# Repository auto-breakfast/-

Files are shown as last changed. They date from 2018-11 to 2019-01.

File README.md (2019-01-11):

Auto_breakfast
===

## 應用情境
應用情境： 以PIC18做為整個作品的核心，以時鐘IC當計時器並在七段顯示器上顯示剩餘時間，再用手機以藍芽做為溝通橋樑傳送資料到PIC18 時間到點以後控制伺服馬達轉動角度來啟動電鍋、吐司機等等 
## 硬體架構
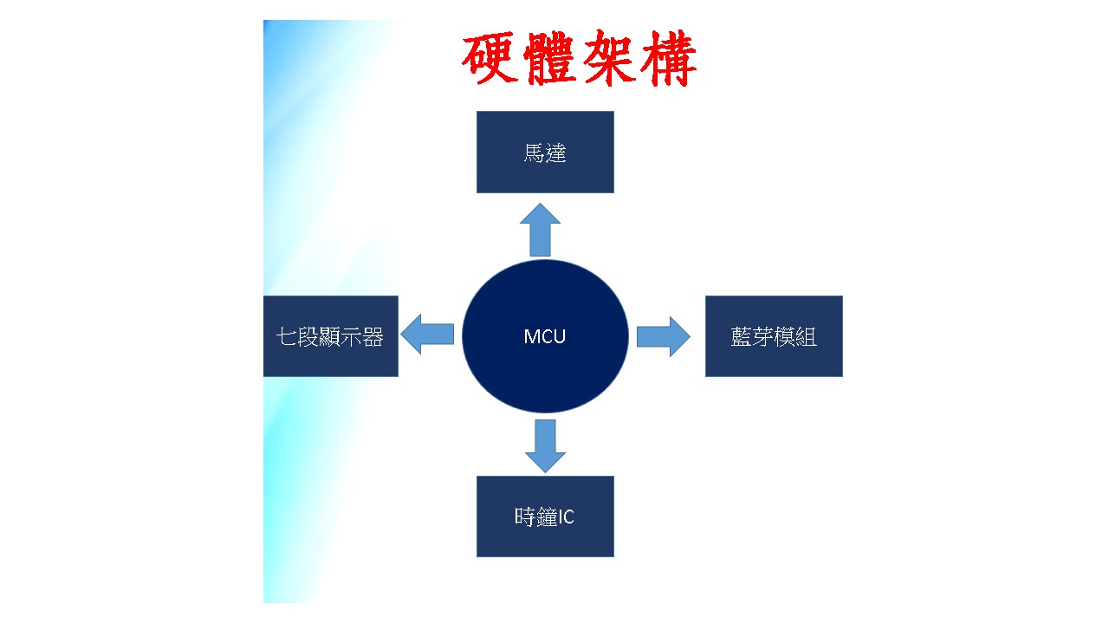
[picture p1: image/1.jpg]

## 軟體架構
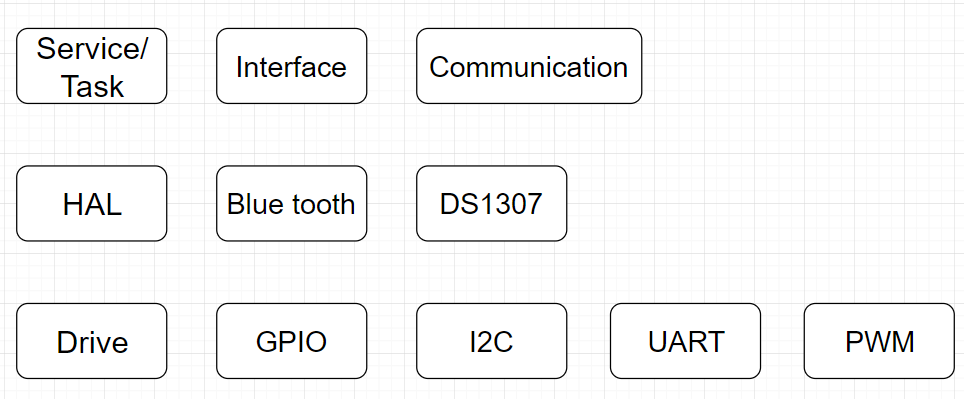
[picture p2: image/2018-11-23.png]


# 使用晶片
 ## MCU [PIC18F4520](https://github.com/auto-breakfast/auto-breakfast/raw/1105192112-patch-%E7%B5%B1%E6%95%B4/doc/39631E.pdf)


# 周邊
 ## 藍芽模組 [HC-05](http://www.electronicaestudio.com/docs/istd016A.pdf)


  ## 時鐘模組 [DS1302](https://github.com/auto-breakfast/auto-breakfast/raw/1105192112-patch-%E7%B5%B1%E6%95%B4/doc/DS1307.pdf)


 ## 伺服馬達 [MG995](https://github.com/auto-breakfast/auto-breakfast/raw/1105192112-patch-%E7%B5%B1%E6%95%B4/doc/MG995_Tower-Pro.pdf)


 ## 七段顯示器 [3641AH BH](https://github.com/auto-breakfast/auto-breakfast/raw/1105192112-patch-%E7%B5%B1%E6%95%B4/doc/3641AHBH.pdf)


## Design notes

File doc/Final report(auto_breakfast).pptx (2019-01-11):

## Auto_breakfast

組長:黃舜琦 組員:黃冠晉、呂睿紘

## 應用情境

- 應用情境： 以PIC18做為整個作品的核心，以時鐘IC當計時器並在七段顯示器上顯示剩餘時間，再用手機以藍芽做為溝通橋樑傳送資料到PIC18 時間到點以後控制伺服馬達轉動角度來啟動電鍋、吐司機等等

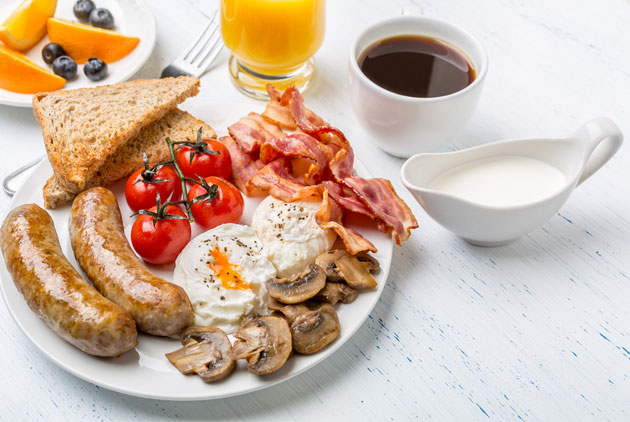
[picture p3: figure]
一張含有 桌, 食物, 杯子, 盤 的圖片 自動產生的描述

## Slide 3

伺服馬達
MG995

PWM

HC-05

GPIO

PIC18F4520

UART

七段顯示

I2C

RTC

## 軟體架構

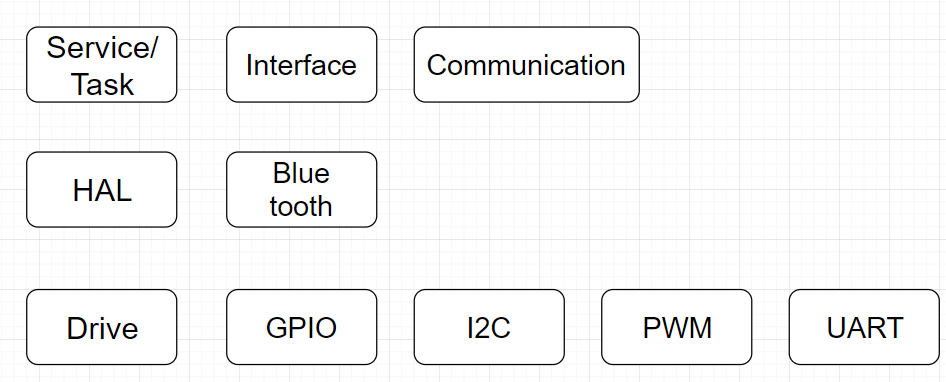
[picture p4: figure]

## 硬體接線圖

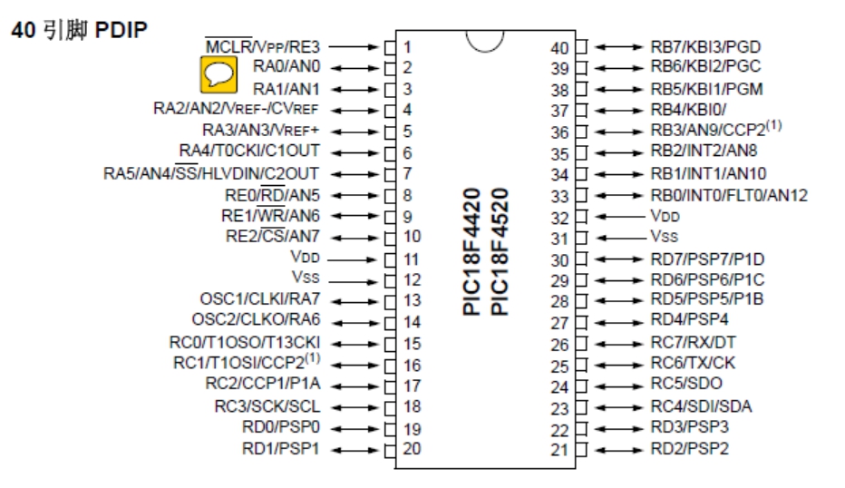
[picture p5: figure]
一張含有 文字 的圖片 自動產生的描述
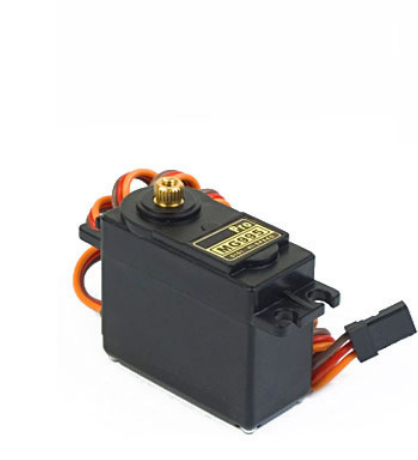
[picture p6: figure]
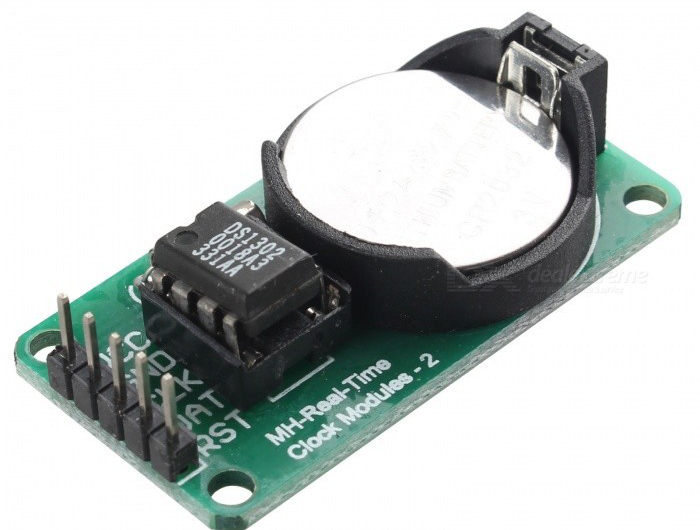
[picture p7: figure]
一張含有 電子用品, 電路 的圖片 自動產生的描述
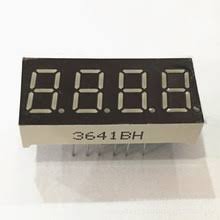
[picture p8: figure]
一張含有 物件 的圖片 自動產生的描述
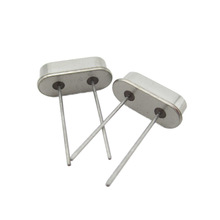
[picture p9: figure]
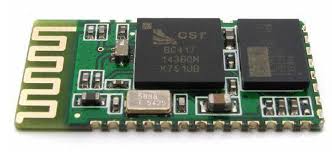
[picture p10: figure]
一張含有 電子用品, 電路 的圖片 自動產生的描述

## 硬體模型

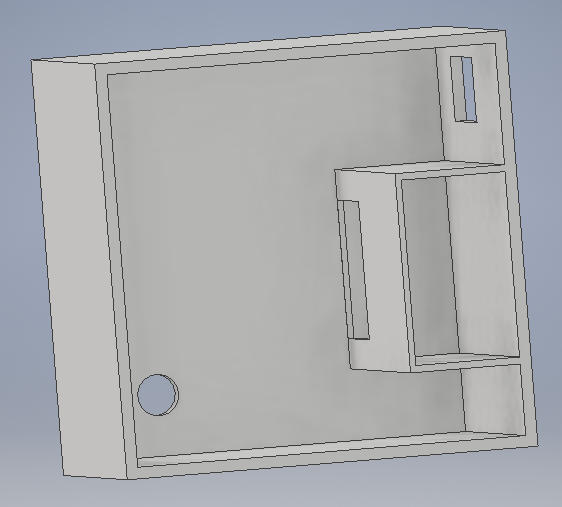
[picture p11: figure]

整體模型架構(固定伺服馬達)
電路板放置模型中
七段顯示器顯示時間處

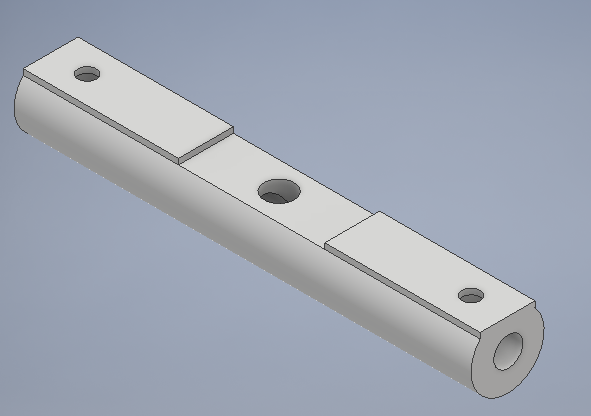
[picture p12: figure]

伺服馬達葉片上碳棒固定管

## 韌體實驗電路

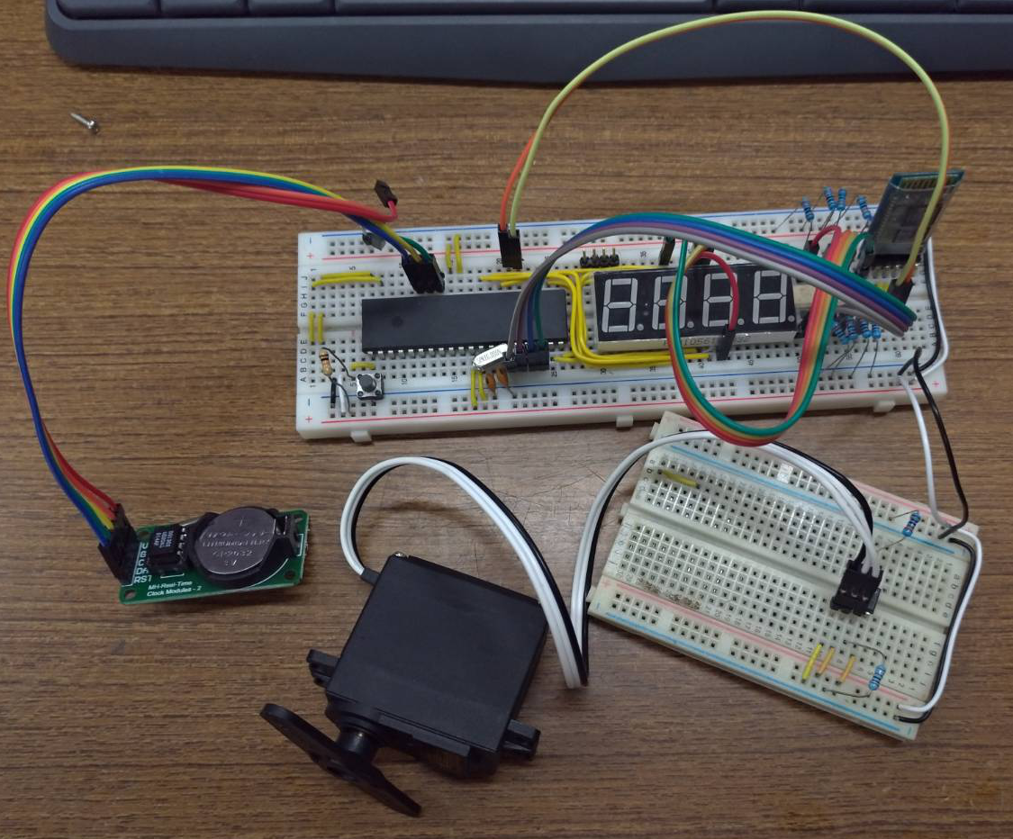
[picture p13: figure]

## 遇到的問題

遇到的問題：
1. 一開始不知道data有無順利輸出。
2. 再和其他程式做結合時，回傳值有時會回傳錯誤(時好時壞)

- UART篇

解決方法：
1. 檢查UART相關registers是否有設定錯誤
2. 使用邏輯分析儀和示波器檢查MCU接收到的資料示是否有錯誤
3. 善加使用debug模式檢查資料輸入及回傳

## 遇到的問題

- PWM篇

遇到的問題：
由於我們所使用的伺服馬達所需的PWM週期為20ms(50Hz)，而PIC18為8位元的處理器，性能較差無法除頻除至50Hz這麼低。

解決方法：
1. 將MCU的頻率降低，但嚴重影響到整體運行效能。(不採用)
2. 使用TIMER去時做出PWM，例:將TIMER設置為0.5ms觸發一次中斷搭配著couter和GPIO輸出。

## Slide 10

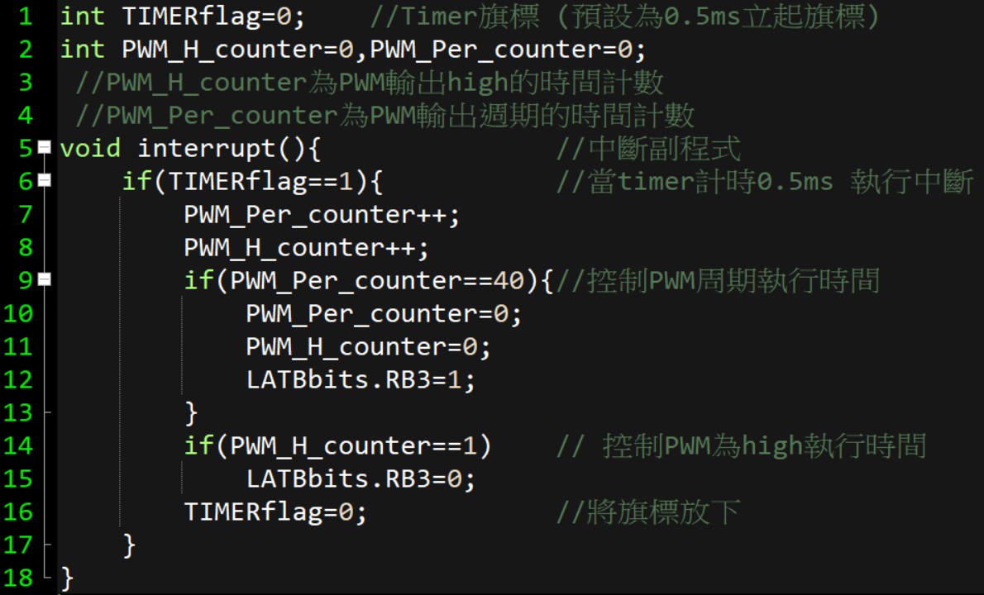
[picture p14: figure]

## 遇到的問題

- RTC篇
在讀Datasheet的時候上面圖說寫地址再給時脈就可以讀去那位址的資訊，可在寫時發現讀不出來，後來去網路上找範例後，發現他是打初始地址然後給8個1BYTE時脈一次把所有時間讀出來，隨後我就用PIC18模擬出波形，解決這問題。

整合篇
當把各自的程式打完做整合時，發現本身在時脈上的設定有所差異，所以在把UART加進去時程式無法正常動作，改好後則是換PWM加進來後的問題，但就像老師說的可以用中斷旗標來控制，後來我有想到可以用TIMER的旗標然後累加控制RTC讓他每10秒來抓值，剩餘的時間給七段顯示器去掃描，這樣的話七段顯示器就不會這麼暗了。

## 學習心得

- 這個學期修這門課以為是會教更多微處理機的延伸課程，結果沒想到是做小專題，壓力其實不小，因為課業、專題，然後又要做小專題，其實是很累的，不過也讓我們學習到如何分配時間去平衡這些課程，我們這組會利用禮拜三下午五六節或是假日的時間一起討論一起做，到最後整合的時候還是發生一些錯誤，讓我們學習到，團隊溝通不只是在人，工具上也是相當重要的。

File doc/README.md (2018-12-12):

# Auto_breakfast
## 核心
* ### MCU [PIC18F4520](https://github.com/auto-breakfast/auto-breakfast/raw/1105192112-patch-%E7%B5%B1%E6%95%B4/doc/39631E.pdf)
{%pdf https://ww1.microchip.com/downloads/en/devicedoc/39631a.pdf %}


## 周邊
* ### 藍芽模組 [HC-02](https://github.com/auto-breakfast/auto-breakfast/raw/1105192112-patch-%E7%B5%B1%E6%95%B4/doc/HC-02.pdf)


* ### 時鐘模組 [DS1307](https://github.com/auto-breakfast/auto-breakfast/raw/1105192112-patch-%E7%B5%B1%E6%95%B4/doc/DS1307.pdf)


* ### 伺服馬達 [MG995](https://github.com/auto-breakfast/auto-breakfast/raw/1105192112-patch-%E7%B5%B1%E6%95%B4/doc/MG995_Tower-Pro.pdf)


* ### 七段顯示器 [3641AH BH](https://github.com/auto-breakfast/auto-breakfast/raw/1105192112-patch-%E7%B5%B1%E6%95%B4/doc/3641AHBH.pdf)

模组尺寸：30×14×7.2（mm）

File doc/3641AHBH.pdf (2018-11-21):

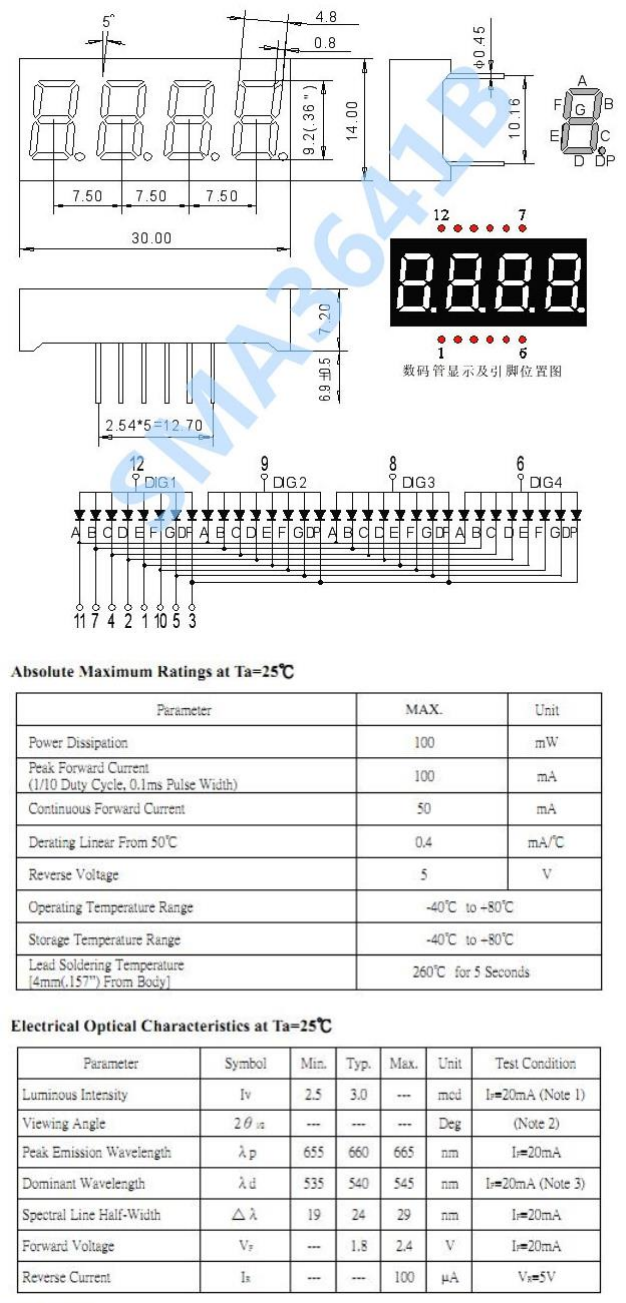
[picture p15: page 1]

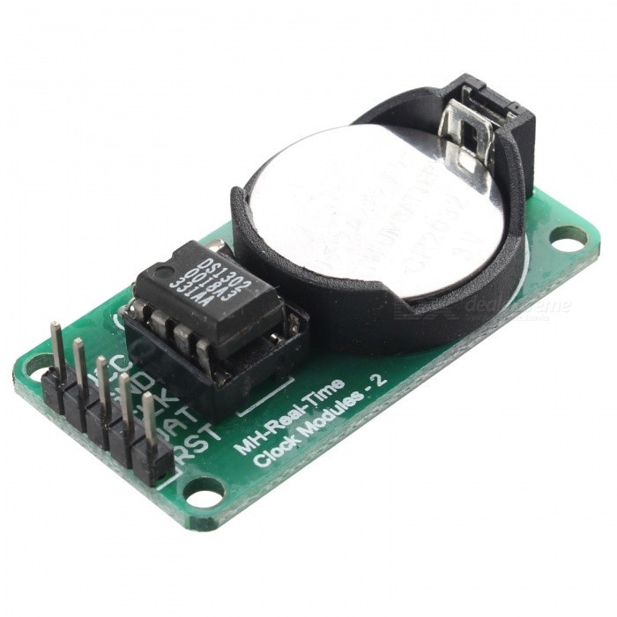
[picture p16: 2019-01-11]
image/DS1302.jpg

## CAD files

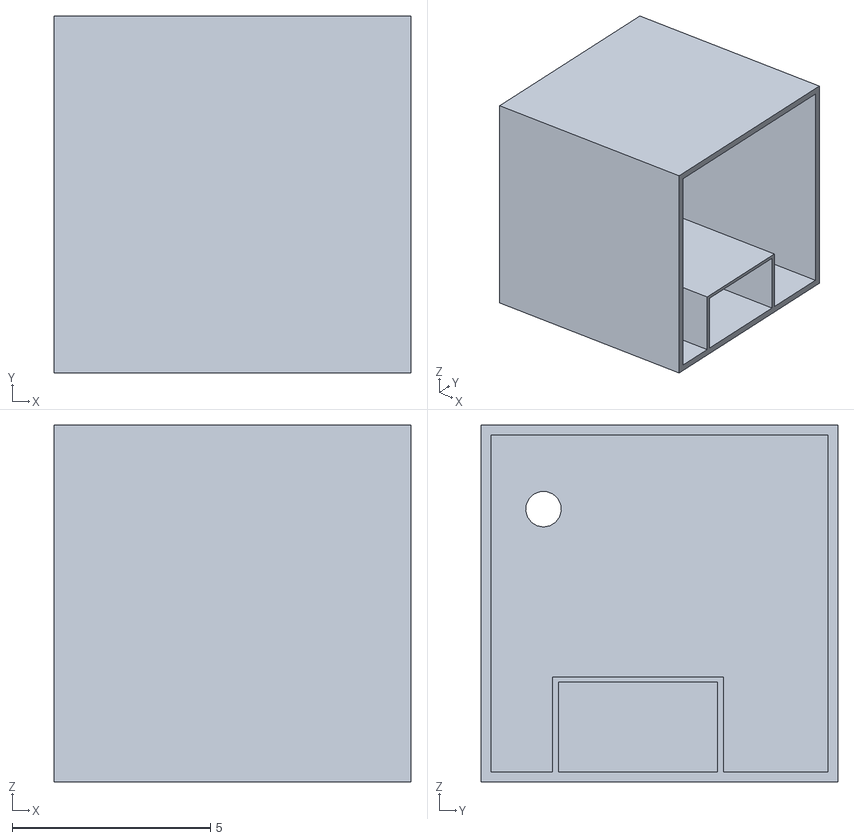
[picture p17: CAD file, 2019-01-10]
image/die man.stl
9.00 x 9.00 x 9.00

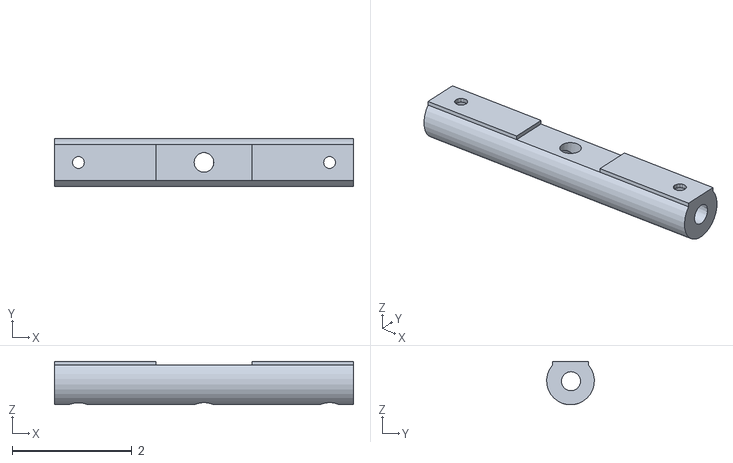
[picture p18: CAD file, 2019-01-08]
image/nature.stl
5.00 x 0.798 x 0.727

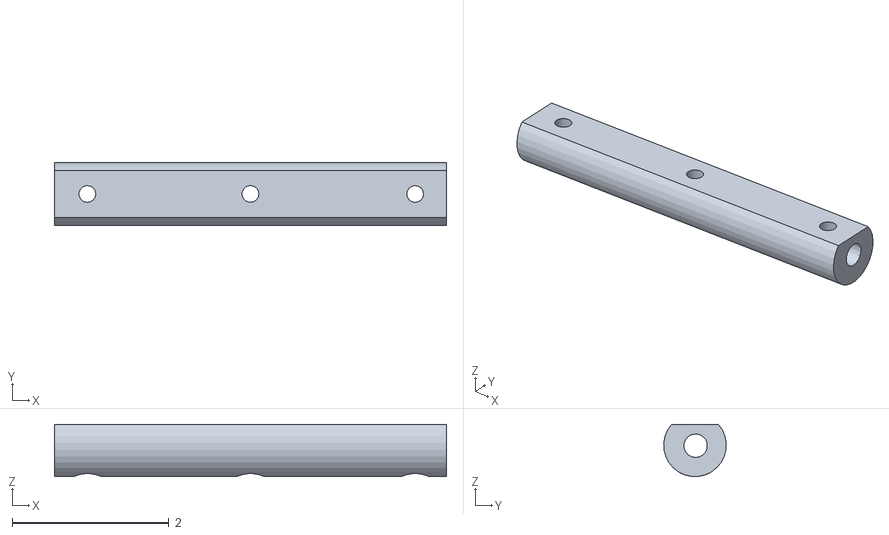
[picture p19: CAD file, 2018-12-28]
image/管子.stl
5.00 x 0.798 x 0.665

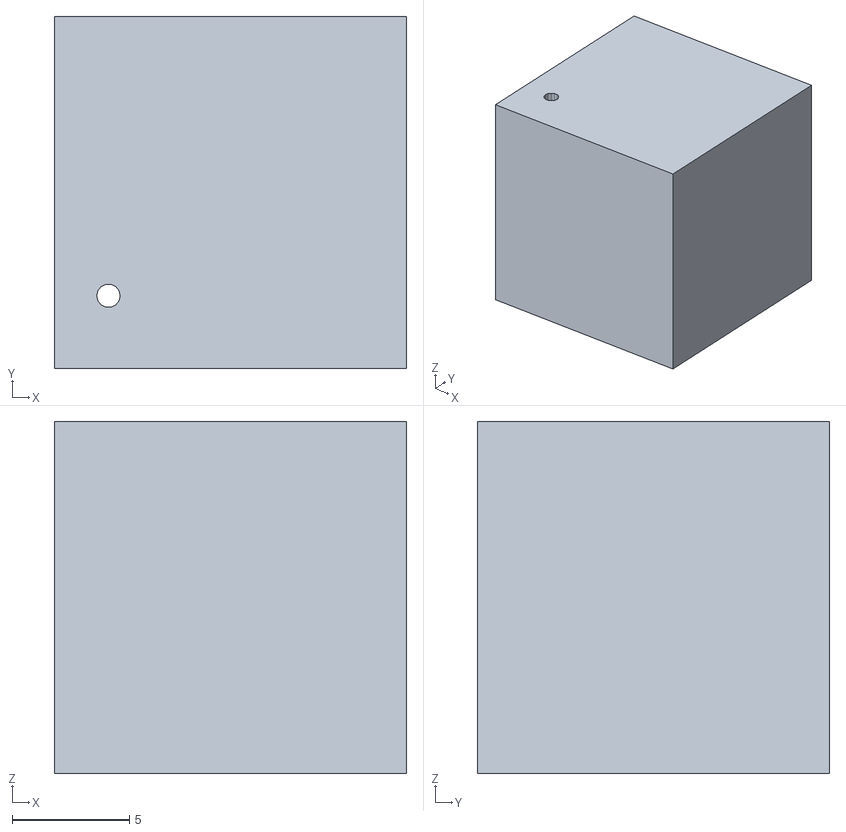
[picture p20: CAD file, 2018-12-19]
image/autobreakfast.stl
15.0 x 15.0 x 15.0

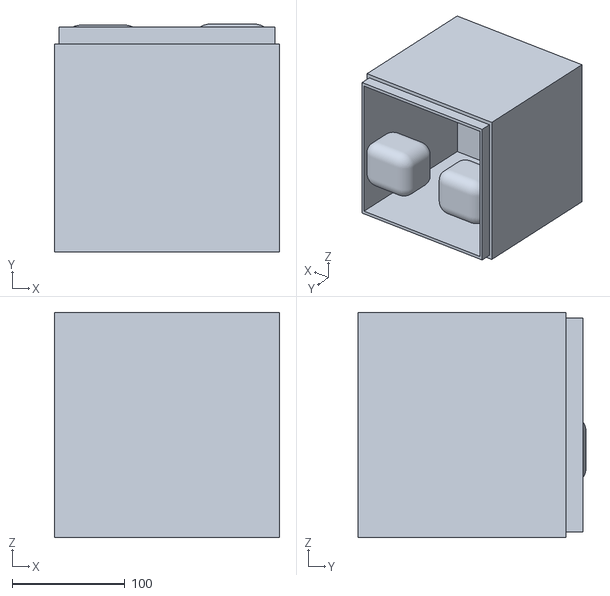
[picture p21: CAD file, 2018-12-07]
image/Mighty Bombul.stl
200.0 x 203.0 x 200.0

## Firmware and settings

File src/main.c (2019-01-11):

/*
 * File:   main.c
 * Author: User
 *
 * Created on 2018年12月19日, 下午 4:15
 */
#include <xc.h>
#include "defines.h"
//#include <stdio.h>
//#include <stdlib.h>
#include <uart.h>
#include "mydelay.h"
#include "RTC.h"
#include "Seven-segment display.h"
//#pragma config statements should precede project file includes.
// Use project enums instead of #define for ON and OFF.

// CONFIG1H
#pragma config OSC = HSPLL      // OSC->HSPLL ?????? 4*PLL = 10 * 4 = 40MHZ
#pragma config FCMEN = OFF      // Fail-Safe Clock Monitor Enable bit (Fail-Safe Clock Monitor disabled)
#pragma config IESO = OFF       // Internal/External Oscillator Switchover bit (Oscillator Switchover mode disabled)
//
//// CONFIG2L
#pragma config PWRT = OFF       // Power-up Timer Enable bit (PWRT disabled)
#pragma config BOREN = SBORDIS  // Brown-out Reset Enable bits (Brown-out Reset enabled in hardware only (SBOREN is disabled))
#pragma config BORV = 3         // Brown Out Reset Voltage bits (Minimum setting)
//
//// CONFIG2H
#pragma config WDT = OFF        // Watchdog Timer Enable bit (WDT disabled (control is placed on the SWDTEN bit))
#pragma config WDTPS = 32768    // Watchdog Timer Postscale Select bits (1:32768)
//
//// CONFIG3H
#pragma config CCP2MX = PORTC   // CCP2 MUX bit (CCP2 input/output is multiplexed with RC1)
#pragma config PBADEN = OFF     // PORTB A/D Enable bit (PORTB<4:0> pins are configured as digital I/O on Reset)
#pragma config LPT1OSC = OFF    // Low-Power Timer1 Oscillator Enable bit (Timer1 configured for higher power operation)
//#pragma config MCLRE = ON       // MCLR Pin Enable bit (MCLR pin enabled; RE3 input pin disabled)
//
//// CONFIG4L





#pragma config STVREN = ON      // Stack Full/Underflow Reset Enable bit (Stack full/underflow will cause Reset)
#pragma config LVP = OFF        // Single-Supply ICSP Enable bit (Single-Supply ICSP disabled)
#pragma config XINST = OFF      // Extended Instruction Set Enable bit (Instruction set extension and Indexed Addressing mode disabled (Legacy mode))
//
//// CONFIG5L
#pragma config CP0 = OFF        // Code Protection bit (Block 0 (000800-001FFFh) not code-protected)
#pragma config CP1 = OFF        // Code Protection bit (Block 1 (002000-003FFFh) not code-protected)
#pragma config CP2 = OFF        // Code Protection bit (Block 2 (004000-005FFFh) not code-protected)
#pragma config CP3 = OFF        // Code Protection bit (Block 3 (006000-007FFFh) not code-protected)
//
//// CONFIG5H
#pragma config CPB = OFF        // Boot Block Code Protection bit (Boot block (000000-0007FFh) not code-protected)
//#pragma config CPD = OFF        // Data EEPROM Code Protection bit (Data EEPROM not code-protected)
//
//// CONFIG6L
#pragma config WRT0 = OFF       // Write Protection bit (Block 0 (000800-001FFFh) not write-protected)
#pragma config WRT1 = OFF       // Write Protection bit (Block 1 (002000-003FFFh) not write-protected)
#pragma config WRT2 = OFF       // Write Protection bit (Block 2 (004000-005FFFh) not write-protected)
#pragma config WRT3 = OFF       // Write Protection bit (Block 3 (006000-007FFFh) not write-protected)
//
//// CONFIG6H
#pragma config WRTC = OFF       // Configuration Register Write Protection bit (Configuration registers (300000-3000FFh) not write-protected)
#pragma config WRTB = OFF       // Boot Block Write Protection bit (Boot block (000000-0007FFh) not write-protected)
#pragma config WRTD = OFF       // Data EEPROM Write Protection bit (Data EEPROM not write-protected)
//
//// CONFIG7L
#pragma config EBTR0 = OFF      // Table Read Protection bit (Block 0 (000800-001FFFh) not protected from table reads executed in other blocks)
#pragma config EBTR1 = OFF      // Table Read Protection bit (Block 1 (002000-003FFFh) not protected from table reads executed in other blocks)
#pragma config EBTR2 = OFF      // Table Read Protection bit (Block 2 (004000-005FFFh) not protected from table reads executed in other blocks)
#pragma config EBTR3 = OFF      // Table Read Protection bit (Block 3 (006000-007FFFh) not protected from table reads executed in other blocks)
//
//// CONFIG7H
#pragma config EBTRB = OFF


//#include <xc.h>

//void OSC_init() // 32MHZ
//{
//    OSCCONbits.IRCF2 = 1;
//    OSCCONbits.IRCF1 = 1;
//    OSCCONbits.IRCF0 = 1;
//    OSCCONbits.SCS1 =0;
//    OSCCONbits.SCS0 =0;
//    while(!OSCCONbits.IOFS); //等待震盪穩定
//    OSCTUNEbits.PLLEN = 1;
//    
//}
void oclillator_initial()  //      Fosc = 40MHz 
{
    OSCCONbits.IOFS=0;        // turn off internal oscillator
    OSCCONbits.SCS0=0;
    OSCCONbits.SCS1=0;        //System Clock Select bits is primary oscillator
}
void main(void) {
    int a = 11;
    int b = 12;
    u8 address,hour,minute;
    u8 str_1[8]={0x01,0x22,0x08,0x04,0x05,0x19,0x02,0x01};
//    u8 str_1[8]={0x00,0x00,0x00,0x00,0x00,0x00,0x00,0x00};
    u8 str[8]={0};
    u8 reciprocal[3]={0};
//    OSC_init();
    delay_ms(2);
    IICinit();
    oclillator_initial();
    initalUART();
//    PR2=253;
//    CCP2CON=0x2C;
//    TRISBbits.RB3=0;
//    T2CON=0x05;
//    CCPR2=0x00;
    
    RTC_write(str_1);
    while(1)
    {
        if(TXFLAG==1)
        {
//            writeuart(uartdata);
            gettime();
            TXFLAG=0;
        }
        RTCread(str);
        hour = (str[2]/16)*10+(str[2]%16);
        minute = (str[1]/16)*10+(str[1]%16);
        Display(hour-time[0],minute-time[1]);
//        delay_ms(10);
        if(hour-time[0]==0&&minute-time[1]&&str[0]-time[2])
        {
            
        }
    }
    return;
}

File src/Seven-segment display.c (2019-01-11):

/*
 * File:   Seven-segment display.c
 * Author: User
 *
 * Created on 2018年12月7日, 上午 9:53
 */


#include "mydelay.h"
#include "Seven-segment display.h"
#include "defines.h"
void Display(u8 hour,u8 minute)
{
    int row;
    int i=0;
    TRISD = 0x00;
    TRISC &= 0x10;
    u8 str[10]={0x3F,0x06,0x5B,0x4F,0x66,0x6C,0x7C,0x07,0x7F,0x6F};
    for (i=0;i<4;i++)
    {
        switch(i) {
            case 0:
                LATCbits.LATC3 = 1;
                LATCbits.LATC0 = 0;
                LATD = ~str[hour/10];
                break;
            case 1:
                LATCbits.LATC2 = 1;
                LATCbits.LATC3 = 0;
                LATD = ~str[hour%10];
                break;
            case 2:
                LATCbits.LATC1 = 1;
                LATCbits.LATC2 = 0;
                LATD = ~str[minute/10];
                break;
            case 3:
                LATCbits.LATC0 = 1;
                LATCbits.LATC1 = 0;
                LATD = ~str[minute%10];
                break;
            default:
                break;
        }
        LATCbits.LATC0 = 0;
                    
    }
}

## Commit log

2018-12-13 設定(尚未使用中斷)
2018-12-13 RX中斷抓值
2018-12-13 TX&RX(OK!)
    手機輸入,手機顯示
2018-12-22 可做動
    但必須依格式輸入
2019-01-11 calculate PWM
    [PWM_T.xlsx]
